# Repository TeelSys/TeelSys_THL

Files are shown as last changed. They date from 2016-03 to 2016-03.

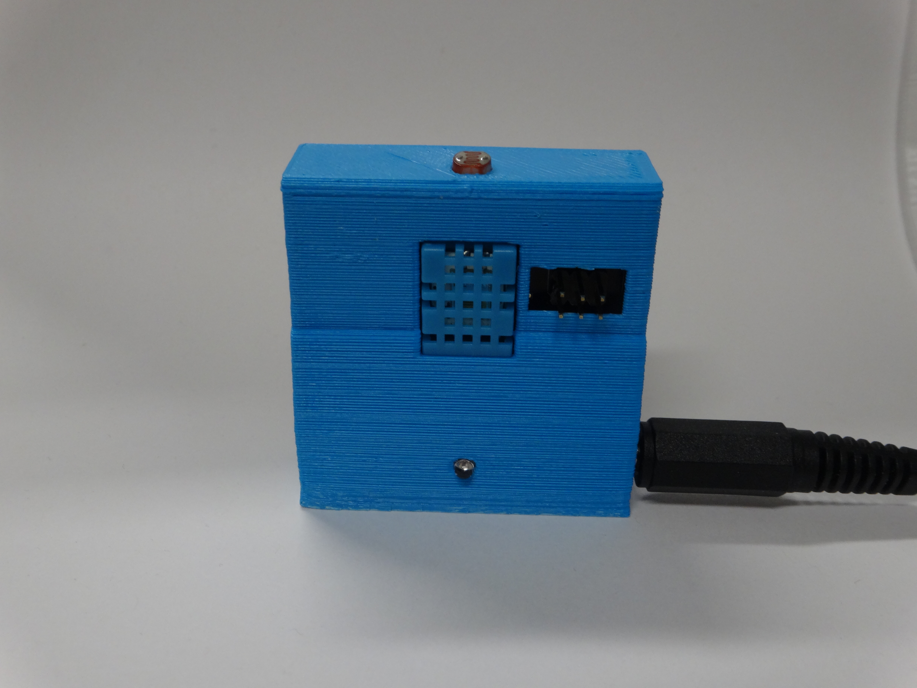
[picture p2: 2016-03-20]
Documentation/Images/DSC02959.JPG

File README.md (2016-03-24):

# TeelSys_THL
ATtiny85 Raspberry Pi Temperature Humidity Light Sensor

View the [GitHub Pages](http://teelsys.github.io/TeelSys_THL/) for this project.

More information regarding this project may be found on the [teelsys.com](http://teelsys.com) blog. Specific entries for this project include the following:

* [I2C Communications between Raspberry Pi and Arduino – Part One](http://teelsys.com/?p=244)
* [I2C Communications between Raspberry Pi and Arduino – Part Two](http://teelsys.com/?p=265)
* [I2C Communications between Raspberry Pi and Arduino – Part Three](http://teelsys.com/?p=314)
* [I2C Communications between Raspberry Pi and Arduino – Part Four](http://teelsys.com/?p=332)
* [I2C Communications between Raspberry Pi and Arduino – Update, BOM, and Source Control](http://teelsys.com/?p=393)

## Release Notes
### Version 0.1.0 - 21 March 2016
* Stable for up to three I2C devices
* Uses the PIGPIO library to bit bang the I2C bus (REF: http://abyz.co.uk/rpi/pigpio/pdif2.html)
* Documentation should be able to get anyone up and running with this version

#### TODO
* Writeup complete documentation from start to finish
  * Add documentation Raspberry Pi Hat (Not a true hat as there is no flash)
  * Add more detailed design documentation 

### Version 0.0.1 - 19 March 2016
* Stable for one I2C device only
* Uses the Raspberry Pi I2C hardware control

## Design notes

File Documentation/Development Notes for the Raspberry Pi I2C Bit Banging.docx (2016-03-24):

# Development Notes for the Raspberry Pi I2C Bit Banging

# Not Used: https://www.raspberrypi.org/forums/viewtopic.php?t=40743

# https://www.raspberrypi.org/forums/viewtopic.php?f=44&t=129678&p=866625

# http://abyz.co.uk/rpi/pigpio/

# PIGPIO Example in C: https://github.com/LeoWhite/OptimusPi/blob/master/src/PiWars/I2C.cpp

Pay attention to the log files to see if they are rotated and compressed.

Log file location is /var/log

REF: https://www.raspberrypi.org/forums/viewtopic.php?f=63&t=134971#p898539

The messages file in the log folder has the same repeating message.

rsyslogd-2007: action 'action 17' suspended, next retry is

## Hardware Used

- QTY 1 - Raspberry Pi Model B (Original Version)
- QTY 1 - WiFi adapter (ebay 150Mbps USB Wifi Wireless Adapter with 8188 cus realtek chip For Raspberry Pi B (http://www.ebay.com/itm/361463422872))
- QTY 1 - 16 GB SD Card (Microcenter (http://www.microcenter.com/product/366176/16GB_microSDHC_Class_10_Flash_Memory_Card))
- QTY 1 – HDMI Monitor
- QTY 1 – Keyboard
- QTY 1 – Mouse
- QTY 1 to 9 – 4 conductor 3.5mm audio cable(s)
- QTY 1 to 9 – Attiny85 I2C Temperature, Humidity, and Light sensor(s)
- QTY 1 - Custom Made Raspberry Pi Hat (Need to document)

## Windows Applications to be used

- Win32DiskImager https://sourceforge.net/projects/win32diskimager/
- PuTTY http://www.putty.org/
- WinSCP https://winscp.net/

## Steps

1. Write Raspbian Image to SD Card
  1.1. Download latest Raspbian Image (Debian Jessie) from https://www.raspberrypi.org/downloads/raspbian/
    - Version: March 2016
    - Release date: 2016-03-18
    - Kernel version: 4.1
    - SHA-1: db41f2a8c6236c0ca9150fe4db2017c09e7871fb
  1.2. Unzip Image
  1.3. Write to SD Card using Win32DiskImager https://sourceforge.net/projects/win32diskimager/
2. Boot up the Raspberry Pi with the prepared SD Card
3. Make a few configuration changes
  3.1. Open a terminal window
  3.2. Type the following command sudo raspi-config
  3.3. Unless you are in the UK you may want to change the “5 Internalisation Options” NOTE: These are the settings I chose. Your choices may be different.
    - “I1 Change Local” Removed “en_GB.UTF-8 UTF-8” Added “en_US.UTF-8 UTF-8” On next screen, I left default local to “None”
    - “I2 Change Timezone” Geographic area: US Time zone: Eastern
    - “I3 Change Keyboard Layout” Left as is since I do have a UK Keyboard
    - “I4 Change Wi-fi Country” US United States
  3.4. Most likely you will want to choose “1 Expand Filesystem” to use the remaining space on your SD Card
    - After the filesystem has been expanded, exit raspi-config and reboot the Raspberry Pi
4. Connect the Raspberry Pi to the Wi-Fi network if you are using wireless by clicking on the network icon on the top right of the screen BTW: If you did not perform the step above to change Wi-Fi country, you may have issues with the Wi-Fi being unreliable. I had this issue earlier and did not realize that was the reason why. It did work most of the time so I did not think much of it.
5. Find the assigned IP Address so we can use PuTTY and WinSCP
  5.1. Open a terminal window
  5.2. Type the following command ifconfig
  5.3. Take note of the wlan0 IP Address

wlan0 Link encap:Ethernet HWaddr xx:xx:xx:xx:xx:xx

inet addr:192.168.1.178 Bcast:192.168.1.255 Mask:255.255.255.0

inet6 addr: xxxx::xxxx:xxxx:xxx:xxxx/64 Scope:Link

UP BROADCAST RUNNING MULTICAST MTU:1500 Metric:1

RX packets:407 errors:0 dropped:203 overruns:0 frame:0

TX packets:94 errors:0 dropped:4 overruns:0 carrier:0

collisions:0 txqueuelen:1000

RX bytes:139109 (135.8 KiB) TX bytes:42920 (41.9 KiB)

  5.4. Now we can use PuTTY to issue commands to the Raspberry Pi. From now on when I refer to opening a terminal, I will be using PuTTY but you are free to use the terminal on the Raspberry Pi.
6. Update and Upgrade to get the latest software changes REF: https://www.raspberrypi.org/documentation/raspbian/updating.md
  6.1. Open a terminal window
  6.2. Type the following command sudo apt-get update
  6.3. Type the following command sudo apt-get upgrade
  6.4. Optionally, you may free up space used in the archives by issuing the following command (I did not apply) sudo apt-get clean  You may run the following command to determine if you need to delete the archives. df -h Look at the free space left in /dev/root.
7. Install PIGPIO REF: http://abyz.co.uk/rpi/pigpio/download.html
  7.1. From a terminal window, issue the following commands
    - wget abyz.co.uk/rpi/pigpio/pigpio.zip
    - unzip pigpio.zip
    - cd PIGPIO
    - make -j4
    - sudo make install
  7.2. Validate that the library installed correctly by running the following command Initially I saw a failed test on TEST 6.1. I removed the Pi Hat so that nothing was connected to pin 22 and reran the tests. This time all of the tests passed.
    - sudo ./x_pigpio # check C I/F
8. Shut down the Raspberry Pi, plug in the Pi Hat, and boot the Raspberry Pi
9. If you installed 9 LEDs on the Pi Hat, you may notice that one of the LEDs is on when the Raspberry Pi boots. Let’s correct that issue by having a script run when the Raspberry Pi boots to put all of LED GPIO Pins in output mode with a low value. NOTE: In my case, GPIO14 (TXD) was high so LED 8 was in the on state
  9.1. Install wiringPi REF: https://projects.drogon.net/raspberry-pi/wiringpi/download-and-install From a terminal window, issue the following commands
    - git clone git://git.drogon.net/wiringPi
    - cd wiringPi
    - git pull origin
    - ./build

NOTE: To compile programs with wiringPi, you need to add:

-lwiringPi

to your compile line(s) To use the Gertboard, MaxDetect, etc.

code (the devLib), you need to also add:

-lwiringPiDev

to your compile line(s).

  9.2. Use WinSCP to connect to the Raspberry Pi and copy setupgpio.sh from the Raspberry Pi folder on the PC to the /home/pi/ folder on the Raspberry Pi
  9.3. Make setupgpio.sh executable by running the following command from the /home/pi directory HINT: You may need to change to the proper folder first. cd .. chmod +x setupgpio.sh
  9.4. Run the script to make certain that all of the LEDs turn off ./setupgpio.sh
  9.5. Run setupgpio.sh on every boot
    - In a terminal window, issue the following command sudo nano /etc/rc.local
    - Add the following lines at the end of the file but before the line “exit 0” # setup the gpio pins for gate control /home/pi/setupgpio.sh
    - Press <Ctrl> O to save the file
    - Press <Ctrl> X to exit nano editor
    - Reboot the Raspberry Pi and verify that the LED(s) go out on boot
10. We need to have the pigpio daemon start when the Raspberry Pi boots REF: https://www.raspberrypi.org/forums/viewtopic.php?f=32&t=103752
  10.1. Use WinSCP to connect to the Raspberry Pi and copy pigpiod from the Raspberry Pi folder on the PC to the /home/pi/ folder on the Raspberry Pi
  10.2. From the terminal window, run the following commands
    - sudo chmod 755 pigpiod
    - sudo cp pigpiod /etc/init.d/pigpiod
    - sudo update-rc.d pigpiod defaults
    - sudo update-rc.d pigpiod enable
  10.3. Reboot the Raspberry Pi
  10.4. When the Raspberry Pi boots back up, verify that the pigpio daemon has started by typing the following command in a terminal window
    - ps aux | grep "pigpiod"
    - The output should be similar to the following

pi@raspberrypi:~ $ ps aux | grep "pigpiod"

root 377 11.1 0.3 9856 1580 ? SLsl 21:02 0:06 /usr/local/bin/pigpiod

11. Now, get the program loaded and running every 5 minutes
  11.1. Use WinSCP to connect to the Raspberry Pi and copy the following files from the Raspberry Pi folder on the PC to the /home/pi/ folder on the Raspberry Pi
    - getdevval_bb
    - thl.config
    - thl.py
  11.2. Edit the thl.config file with your settings
    - SmtpServer – The name of the SMTP Server such as smtp.gmail.com.
    - SmtpPort – The port for the SMTP Server. This is typically 25 or 587.
    - SmtpUserName – The Username for your SMTP server. (Email account to send email.)
    - SmtpPassword – The password for your SMTP server. (Email account to send email.)
    - EmailAddresses – You may add email addresses to send alerts to when there is an error reading a sensor. If you use more than one email address, separate them with a semicolon.
    - AlertSubject – You may leave the default setting or change it. This is the subject of the email that will be sent if there is an error reading one of the sensors.
    - AdafruitIoKey – When you go to io.adafruit.com and setup an account, click on “Settings” > “VIEW AIO KEYS”. Copy the value shown and paste it into the config file.
    - You may also modify the sensor sections to match the hardware that you have and any names that you would like to use for the sensors and feeds. The only restriction on the section names is that they must start with the word “Sensor” in order to be picked up by the Python Script.
      - I2CAddress – This is the decimal representation of the I2C address of the sensor. The valid values are 8 to 119. REF: http://www.totalphase.com/support/articles/200349176-7-bit-8-bit-and-10-bit-I2C-Slave-Addressing
      - SensorName – This is a name used for information messages such as emails and logs.
      - AIOFeed_Temperature – A name to use for a feed on Adafuit.IO for the temperature.
      - AIOFeed_Humidity – A name to use for a feed on Adafuit.IO for the humidity.
      - AIOFeed_Light – A name to use for a feed on Adafuit.IO for the light level.
      - DataFile – The name of a local file to use to collect data for this sensor. This is useful in the event of connection issues with Adafruit.IO.
      - LogFile - The name of a local file to use to collect error messages for this sensor.
      - ModelNumber – This is the model number expected from the sensor. It is used as a final check to ensure that data was properly read.
      - LED_Pin – This is the pin number not the GPIO number of the pin which has an LED connected. The LED will light when the sensor is being read.
      - IsActive – Valid values are True and False. If this is set to True, the Python Script will attempt to read from the sensor.
  11.3. Setup the cron job to run the Python Script once every 5 minutes.
    - From a terminal window, issue the following command. crontab –e
    - Select an editor from the list
    - Add the following line to the file */5 * * * * /home/pi/thl.py
    - Save the file by pressing <Ctrl> O
    - Exit by pressing <Ctrl> X
  11.4. Wait for 6 minutes and check if the data and log files were written and contain information. Also check Adafruit.IO and see if you now have the feeds listed with data.

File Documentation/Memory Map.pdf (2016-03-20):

0 | 1 | 2 | 3 | 4 | 5 | 6 | 7 | 8 | 9 | A | B | C | D | E | F | LED Status 0 | Temperature 1 | T | S | 0 | 0 | 0 | 0 | 0 | 1 | 0 | 0 | 0 | 0 | 0 | 0 | 0 | 3 | Humidity

Light Level
Model Info
Version Info

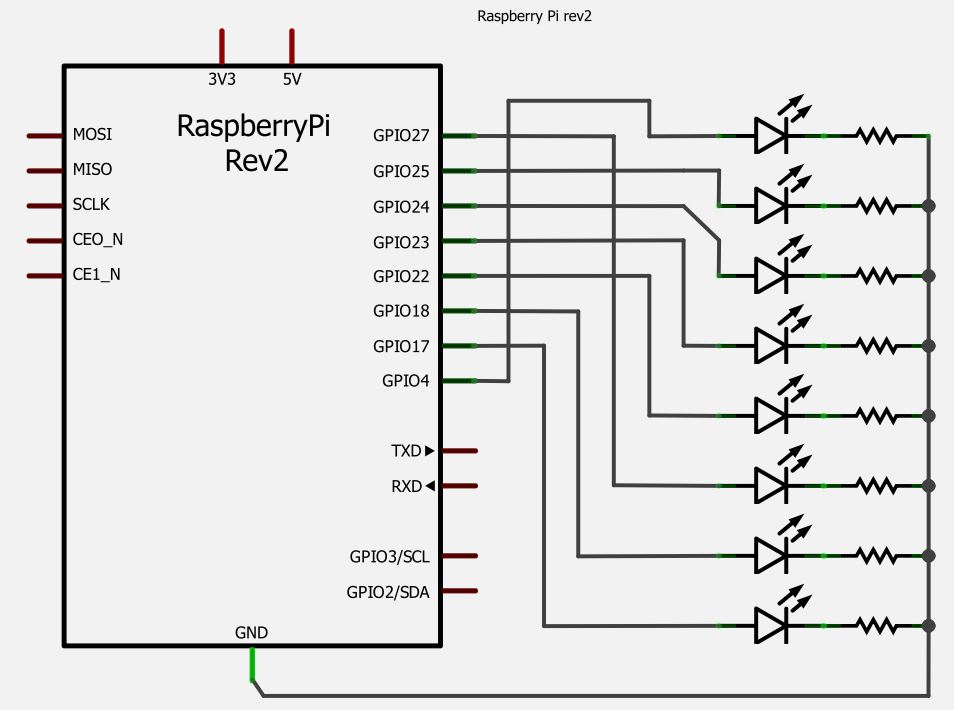
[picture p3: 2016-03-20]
Documentation/Images/F35L2SNHN82KGOY.jpg

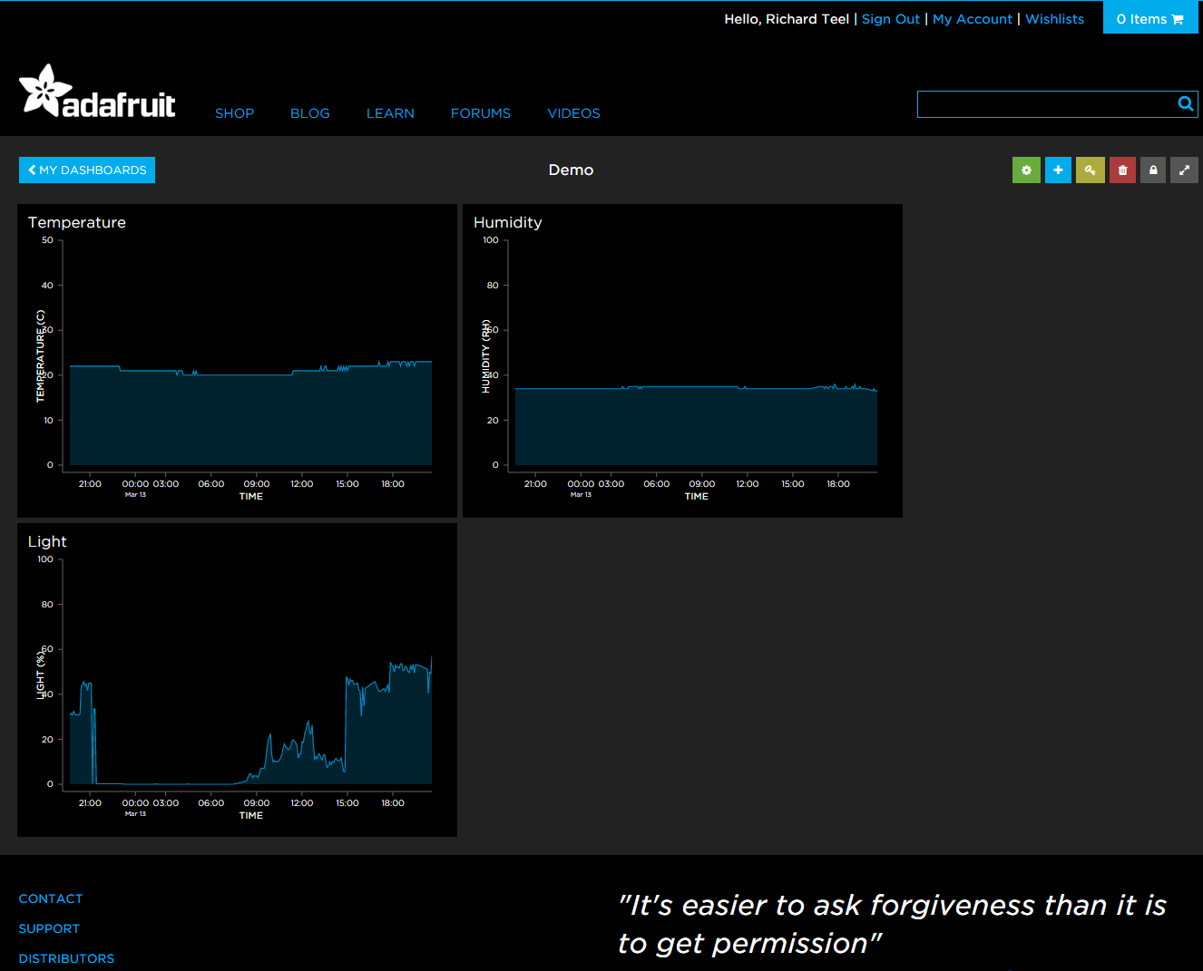
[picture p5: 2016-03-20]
Documentation/Images/adafruit_io.png

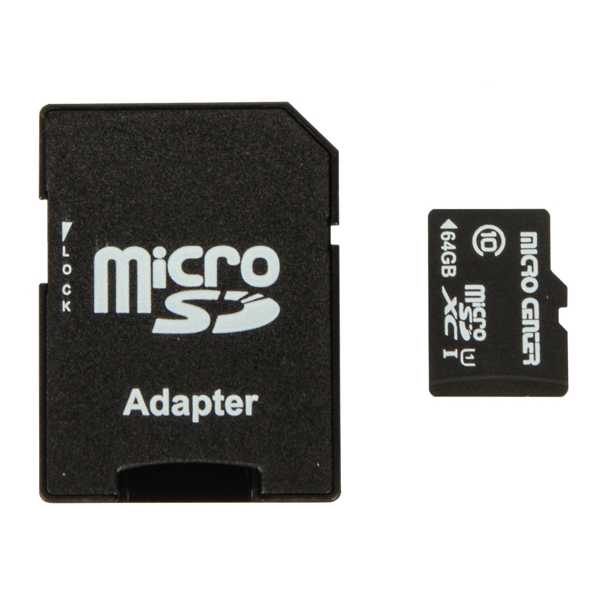
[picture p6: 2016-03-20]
Documentation/Images/MicroSD Card 64GB.jpg

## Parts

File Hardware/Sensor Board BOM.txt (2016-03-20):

Partlist exported from C:/Users/richt/OneDrive/Documents/eagle/Temp, Humidity, and Light Sensor/Sensor Board.sch at 3/19/2016 10:20 AM

Part Value             Device            Package          Description                                  
J-1  4POLE_AUDIO_JACK  4POLE_AUDIO_JACK  4POLE_AUDIO_JACK                                              
J-2  4POLE_AUDIO_JACK  4POLE_AUDIO_JACK  4POLE_AUDIO_JACK                                              
JP1                    PINHD-2X3         2X03             PIN HEADER                                   
LED1                   LED5MM            LED5MM           LED                                          
PH1  D1160_12          D1160_12          D11XX            Photo Sensor Oil Burner Control Applications 
R1   10K               R-US_FLIPFLOP     0805-THM         RESISTOR, American symbol                    
R2   10K               R-US_FLIPFLOP     0805-THM         RESISTOR, American symbol                    
R3   220               R-US_FLIPFLOP     0805-THM         RESISTOR, American symbol                    
SE-1 DHT11THROUGH_HOLE DHT11THROUGH_HOLE DHT11                                                         
U1   ATTINY85-20P      ATTINY85-20P      PDIP08_300MIL    ATMEL ATtiny 85

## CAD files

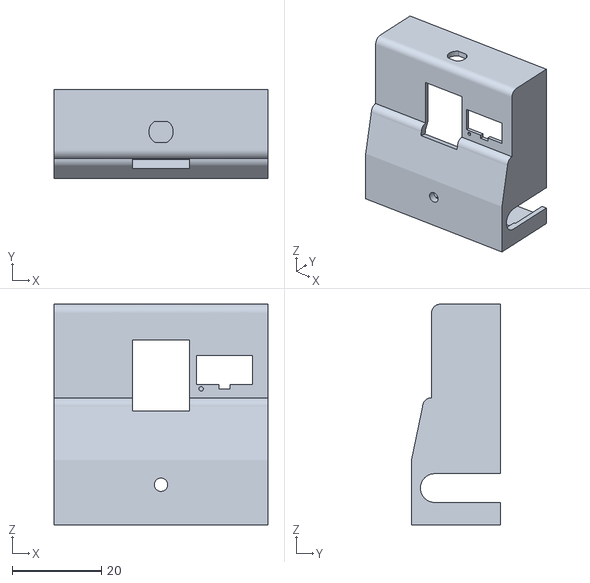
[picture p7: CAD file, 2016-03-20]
Hardware/Case/THL_Case_fixed.stl
48.0 x 20.0 x 49.5

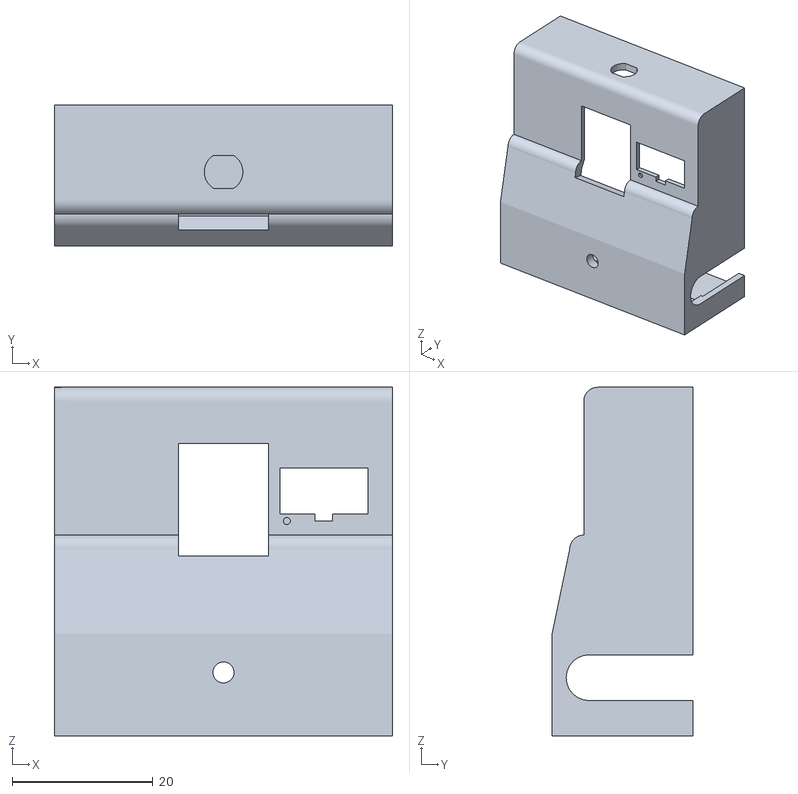
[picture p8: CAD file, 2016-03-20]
Hardware/Case/THL_Case.stl
48.0 x 20.0 x 49.5

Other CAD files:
Hardware/Case/THL_Case.skp

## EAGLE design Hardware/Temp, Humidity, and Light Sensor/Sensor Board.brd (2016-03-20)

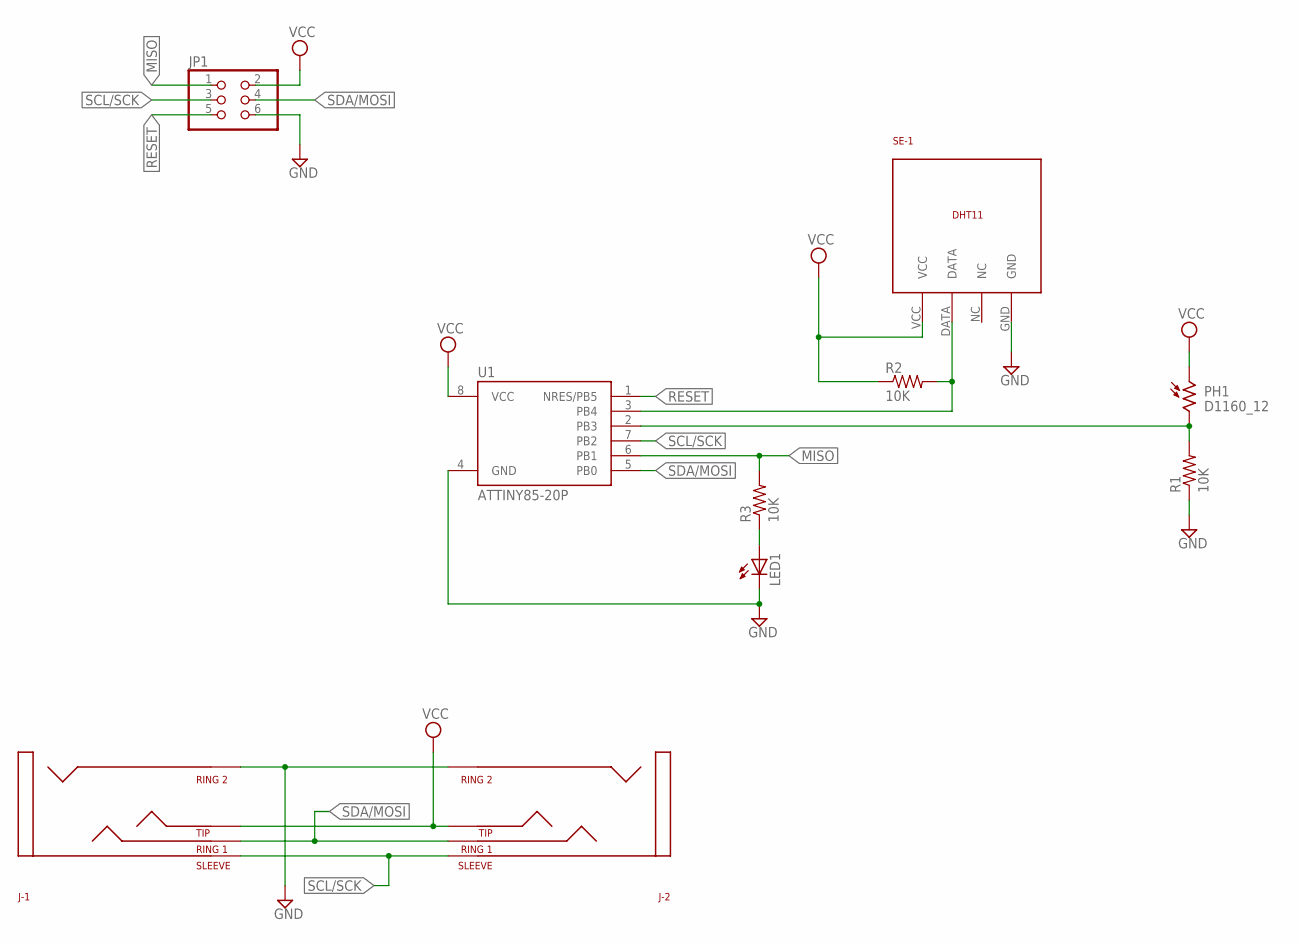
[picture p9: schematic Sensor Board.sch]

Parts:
J-1, J-2: 4POLE_AUDIO_JACK
JP1: PINHD-2X3; 2X03
LED1: LED5MM
PH1: D1160_12; D11XX
R1, R2, R3: 10K; 0805-THM
SE-1: DHT11THROUGH_HOLE; DHT11
U1: ATTINY85-20P; PDIP08_300MIL

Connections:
GND: J-1.RING2, J-2.RING2, JP1.6, LED1.K (C), R1.1, SE-1.GND, U1.4 (GND)
MISO: JP1.1, R3.2, U1.6 (PB1)
unnamed: PH1.2, R1.2, U1.2 (PB3)
unnamed: R2.2, SE-1.DATA, U1.3 (PB4)
unnamed: LED1.A, R3.1
RESET: JP1.5, U1.1 (NRES/PB5)
SCL/SCK: J-1.SLEEVE, J-2.SLEEVE, JP1.3, U1.7 (PB2)
SDA/MOSI: J-1.RING1, J-2.RING1, JP1.4, U1.5 (PB0)
VCC: J-1.TIP1 (TIP), J-2.TIP1 (TIP), JP1.2, PH1.1, R2.1, SE-1.VCC, U1.8 (VCC)

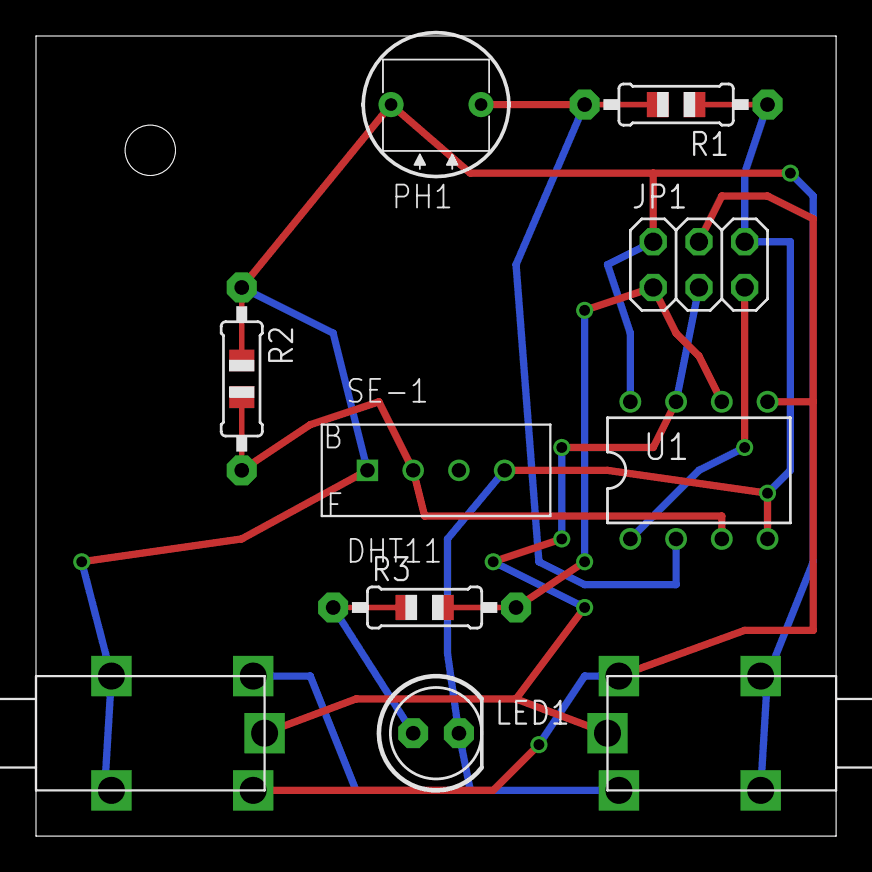
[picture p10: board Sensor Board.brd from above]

Board: 2 copper layers, 44.5 x 44.5 mm, 10 parts (0 on the bottom side), 9 nets.

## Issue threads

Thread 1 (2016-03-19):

Clock Stretching Causes I2C bus to hang

richteel, 2016-03-19:
The bug is in the hardware of the Raspberry Pi. (See [Raspberry Pi I2C clock-stretching bug](http://www.advamation.com/knowhow/raspberrypi/rpi-i2c-bug.html) for more information.)

A [recomendation](https://github.com/rambo/TinyWire/issues/14) is to use the [PiGPIO library](http://abyz.co.uk/rpi/pigpio/index.html) to bit bang the I2C bus.

A [C project](https://github.com/LeoWhite/OptimusPi/blob/master/src/PiWars/I2C.cpp) was found which uses the PiGPIO library. This C project should provide a good start.

# Steps to reproduce with current code base (18 March 2016)
* Currently if only one device is connected the code runs fine. In order to see this issue in action, connect at least two devices to the I2C bus.
* Run commands such as `i2cdetect -y 1` repeatedly. You will see inconsistent behavior with phantom devices appearing, devices disappearing, or no devices at all

richteel, 2016-03-22:
Used bit bang with pigpio library. With current hardware, it supports up to 3 devices over 9 feet/3 meters. This is limited due to the line's RC time constant. May look into shorter cables and test with more devices to see if it will work. Also need to look into possible redesign of hardware although I am happy with the result.

Closed 2016-03-22.

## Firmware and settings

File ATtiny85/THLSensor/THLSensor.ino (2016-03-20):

// Uses DHT from Rob instead of Adafruit
// http://playground.arduino.cc/Main/DHTLib
// http://playground.arduino.cc/Main/DHT11Lib


#include <TinyWireS.h>
#include <dht11.h>

#define SLAVE_ADDRESS 0x32

#define PIN_DHT 4
#define PIN_PHOTORESISTOR A3
#define PIN_LED 1

unsigned long previousMillis = 0;
#define interval 2500

#define bufferSz 32
byte dataBuffer[bufferSz] = { 32 };
uint8_t bufferIdx = 0;
boolean firstByteRead = false;

dht11 DHT11;

// Union used to convert float to byte array
union u_tag {
  byte b[4];
  float fval;
} fdata;

void setup() {
  pinMode(PIN_DHT, INPUT);
  pinMode(PIN_PHOTORESISTOR, INPUT);
  pinMode(PIN_LED, OUTPUT);

  digitalWrite(PIN_LED, HIGH);

  // initialize i2c as slave
  TinyWireS.begin(SLAVE_ADDRESS);

  // define callbacks for i2c communication
  TinyWireS.onReceive(receiveData);
  TinyWireS.onRequest(sendData);

  // Initialize dataBuffer
  for (int i = 0; i < bufferSz; i++) {
    dataBuffer[i] = 0xFF;
  }
  // Set LED to blink on each loop
  dataBuffer[3] = 2;
  // Load Model Info
  // T  S  0  0  0  0  0  1
  // 54 53 30 30 30 30 30 31
  String storeText = F("TS000001");
  bufferIdx = 0x10;
  for (int i = 0; i < storeText.length(); i++) {
    dataBuffer[bufferIdx] = storeText[i];
    bufferIdx++;
  }
  // Load Version Info
  // 0  0  0  0  0  0  0  3
  // 30 30 30 30 30 30 30 33
  storeText = F("00000003");
  bufferIdx = 0x18;
  for (int i = 0; i < storeText.length(); i++) {
    dataBuffer[bufferIdx] = storeText[i];
    bufferIdx++;
  }
}

void loop() {
  TinyWireS_stop_check();
  
  unsigned long currentMillis = millis();

  if (currentMillis - previousMillis >= interval) {
    previousMillis = currentMillis;

    if (dataBuffer[3] == 2) {
      digitalWrite(PIN_LED, !digitalRead(PIN_LED));
    }

    ReadDHT();
    ReadLightLevel();
  }
}

// callback for received data
void receiveData(uint8_t byteCount) {
  if (byteCount != 1)
  {
    // Sanity-check
    return;
  }

  while (TinyWireS.available()) {
    bufferIdx = TinyWireS.receive();
    firstByteRead = false;

    SetLedStatus();
  }
}

// callback for sending data
void sendData() {
  if (firstByteRead) {
    bufferIdx++;
  }

  firstByteRead = true;

  if(bufferIdx < 0 || bufferIdx >= bufferSz) {
    TinyWireS.send(0xFF);
    return;
  }

  TinyWireS.send(dataBuffer[bufferIdx]);
}

void ReadDHT() {
  int chk = DHT11.read(PIN_DHT);

  if(!chk==DHTLIB_OK) {
    return;
  }
  
  float humidity = (float)DHT11.humidity;
  float temperatureCelsius = (float)DHT11.temperature;
  
  SaveFloatToBuffer(0x04, temperatureCelsius);
  SaveFloatToBuffer(0x08, humidity);
}

void ReadLightLevel() {
  int photocellReading = analogRead(PIN_PHOTORESISTOR);
  float lightReading = ((float)photocellReading / 1023.0) * 100.0;
  SaveFloatToBuffer(0x0C, lightReading);
}

void SaveFloatToBuffer(uint8_t bufIdx, float val) { 
  dataBuffer[bufIdx] = 0;
  dataBuffer[bufIdx + 1] = 0;
  dataBuffer[bufIdx + 2] = 0;
  dataBuffer[bufIdx + 3] = 0;
  
  fdata.fval = val;

  dataBuffer[bufIdx] = fdata.b[3];
  dataBuffer[bufIdx + 1] = fdata.b[2];
  dataBuffer[bufIdx + 2] = fdata.b[1];
  dataBuffer[bufIdx + 3] = fdata.b[0];
  
  //dataBuffer[bufIdx] = (int)val;
}

void SetLedStatus() {
  if (bufferIdx > 2)
    return;

  dataBuffer[3] = 2;
  if (bufferIdx < 2) {
    digitalWrite(PIN_LED, bufferIdx);
    dataBuffer[3] = 0;
    if (digitalRead(PIN_LED) == HIGH) {
      dataBuffer[3] = 1;
    }
  }
}

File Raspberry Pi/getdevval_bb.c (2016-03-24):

/*
	* gcc -Wall -pthread -o getdevval_bb getdevval_bb.c -lpigpio -lrt -lm
	* gcc -Wall -pthread -o getdevval_bb getdevval_bb.c -lpigpiod_if2 -lrt
	* ./getdevval_bb 16 0
	*
	* sudo pigpiod
*/

// #include <linux/i2c-dev.h>
// #include <pigpio.h>

/*
#include <string.h>
#include <errno.h>
#include <sys/ioctl.h>
#include <fcntl.h>
#include <math.h>
*/
#include <stdio.h>
#include <stdlib.h>
#include <unistd.h>
#include <pigpiod_if2.h>

#define CMD_GET_TEMPERATURE 1
#define CMD_GET_HUMIDITY 2
#define CMD_SET_LIGHT 3
#define CMD_SET_LED_ON 4
#define CMD_SET_LED_OFF 5
#define CMD_SET_LED_FLASH 6
#define CMD_GET_MODEL 250
#define CMD_GET_VERSION 251
#define CMD_GET_HELLO_WORLD 254

// The GPIO pins to use for the 'External' I2C bus
#define SDA_PIN 2
#define SDL_PIN 3
#define BAUD 5000

// Function Headers
char receiveChar(unsigned char deviceAddress);
float receiveFloat(unsigned char deviceAddress);
int receiveInt(unsigned char deviceAddress);
void receiveString(unsigned char deviceAddress, char *buf, int bufSize);
int sendCommand(unsigned char deviceAddress, unsigned char cmdCode);

// Unions
union u_tag {
	char b[4];
	float fval;
} fdata;

// Global Variables
int startHandle;
unsigned int openHandle;
int pi;

// Main program
int main(int argc, char** argv) {
	int device_id;
	int command;
	
	if (argc != 3) {
    fprintf(stderr, "Usage getdevval <device id> <command>\n");
    exit(1);
  }
  
  if (0 == sscanf(argv[1], "%d", &device_id)) {
    fprintf(stderr, "Invalid device id \"%s\"\n", argv[1]);
    exit(1);
  }
  
  if(0 == sscanf(argv[2], "%d", &command)) {
    fprintf(stderr, "Invalid command \"%s\"\n", argv[2]);
    exit(1);
  }
  
  // Initialize/setup i2c
  int pi = pigpio_start(NULL, NULL);
  if(pi != 0) {
    fprintf(stderr, "Failed to connect to pigpiod, is it running?\nTo start it, run the following command.\n\tsudo pigpiod\n");
    exit(1);
  }
  
  // Open bit banging I2C on standard I2C pins
  int h = bb_i2c_open(pi, SDA_PIN, SDL_PIN, BAUD);
  if (h) {
  	switch(h) {
  		case PI_BAD_USER_GPIO:
  			fprintf(stderr, "Failed to open bit bang port (PI_BAD_USER_GPIO)\n");
  			break;
  		case PI_BAD_I2C_BAUD:
  			fprintf(stderr, "Failed to open bit bang port (PI_BAD_I2C_BAUD)\n");
  			break;
  		case PI_GPIO_IN_USE:
  			fprintf(stderr, "Failed to open bit bang port (PI_GPIO_IN_USE)\n");
  			break;
  		case -2011:	// pigif_unconnected_pi
  			fprintf(stderr, "Failed to open bit bang port (pigif_unconnected_pi)\n");
  			break;
  		default:
  			fprintf(stderr, "Failed to open bit bang port (%d)\n", h);
  			break;
  	}
    exit(1);
  }
  
	sendCommand(device_id, command);
	
	char buf[9];
	int bufSize = sizeof(buf)/sizeof(buf[0]);
	int ledState = 0;
	float temperature = 0.0;
	float percentHumidity = 0.0;
	float lightLevel = 0.0;
	
  switch(command) {
  	case 0x00:	// LED OFF
  		break;
  	case 0x01:	// LED ON
  		break;
  	case 0x02:	// LED FLASH
  		break;
  	case 0x03:	// LED STATE
		  ledState = receiveInt(device_id);
		  printf("%d", ledState);
  		break;
  	case 0x04:	// TEMPERATURE
		  temperature = receiveFloat(device_id);
		  printf("%1.2f", temperature);
  		break;
  	case 0x08:	// HUMIDITY
		  percentHumidity = receiveFloat(device_id);
		  printf("%1.2f", percentHumidity);
  		break;
  	case 0x0C:	// LIGHT LEVEL
		  lightLevel = receiveFloat(device_id);
		  printf("%1.2f", lightLevel);
  		break;
  	case 0x10:	// MODEL
  		receiveString(device_id, buf, bufSize);
  		printf("%s", buf);
  		break;
  	case 0x18:	// VERSION
  		receiveString(device_id, buf, bufSize);
  		printf("%s", buf);
  		break;
  	default:
  		break;
  }
  
  // We want to stop the pigpio connection when the program exits
  bb_i2c_close(pi, SDA_PIN);
  pigpio_stop(pi);
  	
  exit(0);
}

char receiveChar(unsigned char deviceAddress) {
	char ReadBuf[256];
	char CmdBuf[] = {4, deviceAddress,  // Chip address
                       2, 6, 1, 3,    // Write command to sensor
                       0 // EOL
                       };
                       
	int bytesRead = bb_i2c_zip(pi, SDA_PIN, CmdBuf, sizeof(CmdBuf), ReadBuf, sizeof(ReadBuf));
	
	if(bytesRead < 0) {
		fprintf(stderr, "Failed to read from device (Device=%d / Error Code=%d\n", deviceAddress, bytesRead);
	}
	
  char retVal = 0x00;
  
  if (bytesRead == 1) {
  	retVal=ReadBuf[0];
  }
  
	usleep(10000);
  return retVal;
}

float receiveFloat(unsigned char deviceAddress) {	
	fdata.b[3] = 0;
	fdata.b[2] = 0;
	fdata.b[1] = 0;
	fdata.b[0] = 0;
	
	fdata.b[3] = receiveChar(deviceAddress);
	fdata.b[2] = receiveChar(deviceAddress);
	fdata.b[1] = receiveChar(deviceAddress);
	fdata.b[0] = receiveChar(deviceAddress);
	
	return fdata.fval;
}

int receiveInt(unsigned char deviceAddress) {
  return (int)receiveChar(deviceAddress);
}

void receiveString(unsigned char deviceAddress, char *buf, int bufSize) {
  int charCount=0;
  
  for(charCount=0; charCount<bufSize-1; charCount++) {
		buf[charCount] = receiveChar(deviceAddress);
	}
	buf[bufSize-1] = 0x00;
}

int sendCommand(unsigned char deviceAddress, unsigned char cmdCode) {
	/*
			unsigned SDA: 0-31 (as used in a prior call to bbI2COpen)
			char	*inBuf: pointer to the concatenated I2C commands, see below
			unsigned inLen: size of command buffer
			char	*outBuf: pointer to buffer to hold returned data
			unsigned outLen: size of output buffer
	*/
	
	char ReadBuf[1];
	char CmdBuf[] = {4, deviceAddress,  // Chip address
                       2, 7, 1, cmdCode, 3,    // Write command to sensor
                       0 // EOL
                       };
                       
	int bytesRead = bb_i2c_zip(pi, SDA_PIN, CmdBuf, sizeof(CmdBuf), ReadBuf, sizeof(ReadBuf));
	
	if(bytesRead < 0) {
		fprintf(stderr, "Failed to send command (Device=%d / Command=%d / Error Code=%d\n", deviceAddress, cmdCode, bytesRead);
	}
	
	usleep(10000);
	return 0;
}

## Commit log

2016-03-19 Initial File Load
    [Addresses.xlsx, Memory Map.xlsx, Sensor Board.brd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]
2016-03-19 Adding files for the case
    [THL_Case.skp, THL_Case.stl, THL_Case_fixed.stl]
2016-03-19 Added BOM
2016-03-20 Fixed line endings which were corrupted by Git.
    Added some missing and new files as well.
    [THL_Case.stl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]
2016-03-22 * Stable for up to three I2C devices * Uses the PIGPIO library to bit bang the I2C bus (REF: http://abyz.co.uk/rpi/pigpio/pdif2.html) * Documentation should be able to get anyone up and running with 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
